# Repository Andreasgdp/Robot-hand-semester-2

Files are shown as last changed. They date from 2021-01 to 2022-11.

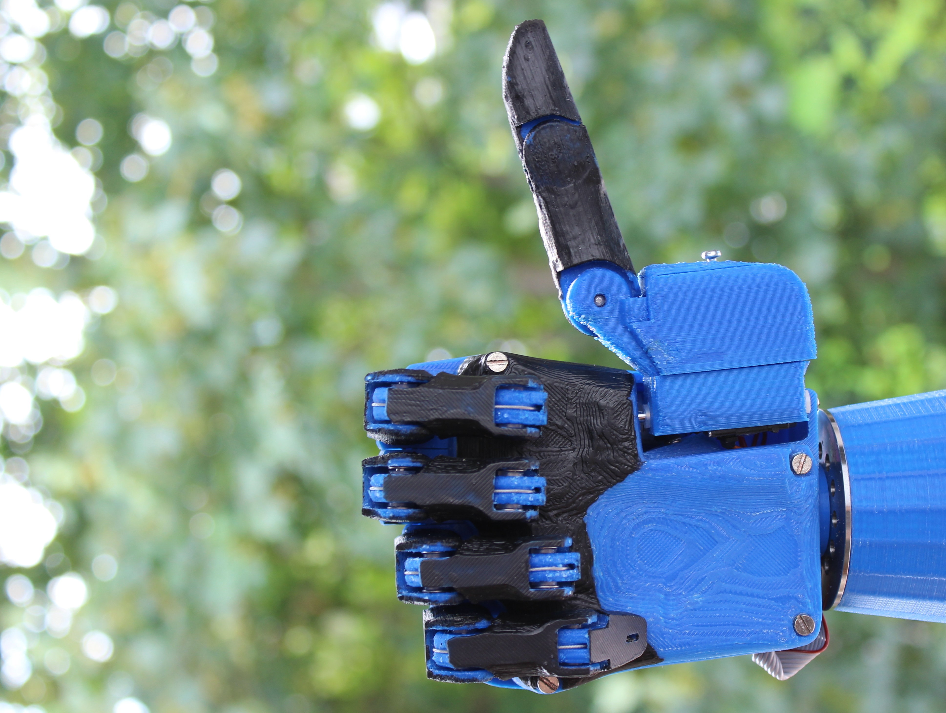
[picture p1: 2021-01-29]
images_readme/robot_hand.jpg

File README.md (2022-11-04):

<!--
*** Thanks for checking out this README Template. If you have a suggestion that would
*** make this better, please fork the repo and create a pull request or simply open
*** an issue with the tag "enhancement".
*** Thanks again! Now go create something AMAZING! :D
***
***
***
*** To avoid retyping too much info. Do a search and replace for the following:
*** andreasgdp, Robot-hand-semester-2, AndreasGuldberg, andreasgdp@gmail.com
-->

<!-- PROJECT SHIELDS -->
<!--
*** I'm using markdown "reference style" links for readability.
*** Reference links are enclosed in brackets [ ] instead of parentheses ( ).
*** See the bottom of this document for the declaration of the reference variables
*** for contributors-url, forks-url, etc. This is an optional, concise syntax you may use.
*** https://www.markdownguide.org/basic-syntax/#reference-style-links
-->
[][contributors-url]
[][forks-url]
[][stars-url]
[][issues-url]
[][license-url]
[][linkedin-url]
<!-- ABOUT THE PROJECT -->
## About The Project
<p align="center"> 
Gripper 
</p>

### Abstract
In this project, we have worked to make a gripper that can be mounted on and integrated
with a UR5 robot. The gripper has been 3D modelled, 3D printed and mounted on a UR5 robot.
The gripper is controlled by the movements of a motor located in the center of the gripper. The engine receives signals
to go in each direction at varying speed from an electrical circuit which receives signals from
a C++ program running on a Raspberry Pi. We have made a URCaps extension for ours
grabs a UR5. We have made an XML-RPC server running on a Raspberry Pi to be able to
communicate with the URCaps extension. With this XML-RPC communication we have the opportunity to
to control the gripper from a UR program running on the UR5 robot with our URCaps extension.
We have also made a GUI running alongside the server on the Raspberry Pi that we can use
to control the gripper directly.

### Built With

* [C++]()
* [Pure manpower]()

<!-- MARKDOWN LINKS & IMAGES -->
<!-- https://www.markdownguide.org/basic-syntax/#reference-style-links -->
[contributors-shield]: https://img.shields.io/github/contributors/andreasgdp/Robot-hand-semester-2.svg?style=flat-square
[contributors-url]: https://github.com/andreasgdp/Robot-hand-semester-2/graphs/contributors
[forks-shield]: https://img.shields.io/github/forks/andreasgdp/Robot-hand-semester-2.svg?style=flat-square
[forks-url]: https://github.com/andreasgdp/Robot-hand-semester-2/network/members
[stars-shield]: https://img.shields.io/github/stars/andreasgdp/Robot-hand-semester-2.svg?style=flat-square
[stars-url]: https://github.com/andreasgdp/Robot-hand-semester-2/stargazers
[issues-shield]: https://img.shields.io/github/issues/andreasgdp/Robot-hand-semester-2.svg?style=flat-square
[issues-url]: https://github.com/andreasgdp/Robot-hand-semester-2/issues
[license-shield]: https://img.shields.io/github/license/andreasgdp/Robot-hand-semester-2.svg?style=flat-square
[license-url]: https://github.com/andreasgdp/Robot-hand-semester-2/blob/master/LICENSE.txt
[linkedin-shield]: https://img.shields.io/badge/-LinkedIn-black.svg?style=flat-square&logo=linkedin&colorB=555
[linkedin-url]: https://www.linkedin.com/in/andreas-g-d-petersen-11707518b/
[product-screenshot]: images_readme/robot_hand.jpg

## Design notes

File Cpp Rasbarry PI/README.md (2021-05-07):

# Cpp program to run on Rasberry PI and PC
1. Create a QT application to get a GUI.
2. In the .pro file of the project you must include this:
-----------------------------------------------
  # WiringPi Libary
  INCLUDEPATH += /home/pi/sysroot/usr/include/
  LIBS += -L"/home/pi/sysroot/usr/lib"
  LIBS += -lwiringPi
-----------------------------------------------
This is the the library that gives control of the PI.

3. This library may need to be build in the terminal. Follow this: http://wiringpi.com/download-and-install/
4. To get the server working you must build the XML-RPC library. Follow this: http://xmlrpc-c.sourceforge.net 
5. Again you must include the library in the .pro file
-----------------------------------------------
  # XML-RPC Library
  LIBS += -Lusr/local/lib/ -lxmlrpc++
  LIBS += -Lusr/local/lib/ -lxmlrpc_util++
  LIBS += -Lusr/local/lib/ -lxmlrpc_server++
  LIBS += -Lusr/local/lib/ -lxmlrpc_server_abyss++
-----------------------------------------------

6. Now you should have everything needed to make the program.

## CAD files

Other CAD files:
3D-model gripper/Parts/Griber v1.f3d
3D-model gripper/Parts/Griber v2.f3d
3D-model gripper/Parts/Griber v21.f3d
3D-model gripper/Parts/Griber v3.f3d
3D-model gripper/Parts/Griber v4.f3d
3D-model gripper/Parts/Griber v5.f3d
3D-model gripper/Parts/Griber v6.f3d
3D-model gripper/Parts/Griber v7.f3d
3D-model gripper/Parts/Gripper n' Holder v1.f3z
3D-model gripper/Parts/Gripper n' Holder v5.f3z
3D-model gripper/Parts/Test motor v1.f3d
3D-model gripper/Parts/ToolFlange now with constraints v7.f3d
3D-model gripper/Parts/ToolFlange now with constraints v8.f3d
3D-model gripper/Parts/motor mount v9.f3z

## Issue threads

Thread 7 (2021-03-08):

First prototype of 3D-model of gripper in fusion

Andreasgdp, 2021-03-08:
**Describe the solution you'd like**
A clear and concise description of what you want to happen.

- Requirements for gripper
    - 2 active fingers

- [ ]  Create 3D-model of finges
- [ ]  Create 3D-model of Base
- [ ]  Use joints to attatch fingers to base

**Additional context**
Add any other context or screenshots about the feature request here.

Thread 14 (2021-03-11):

Create a TCP socket and server

Piekut99, 2021-03-11:
**Is your feature request related to a problem? Please describe.**
A clear and concise description of what the problem is. Ex. I'm always frustrated when [...]

**Describe the solution you'd like**
A clear and concise description of what you want to happen.

**Describe alternatives you've considered**
A clear and concise description of any alternative solutions or features you've considered.

**Additional context**
Add any other context or screenshots about the feature request here.

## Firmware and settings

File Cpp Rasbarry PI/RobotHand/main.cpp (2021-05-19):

#include "MainWindow.h"
#include <QApplication>

#define WIN32_LEAN_AND_MEAN

#include <iostream>
#include <stdexcept>
#include <cassert>
#include <string>
#include <thread>
#include "gripper.h"
#include <wiringPi.h> /* include wiringPi library */
#include <stdio.h>
#include <softPwm.h>  /* include header file for software PWM */

#ifdef _WIN32
#include <windows.h>
#else
#include <unistd.h>
#endif

#include <xmlrpc-c/base.hpp>
#include <xmlrpc-c/registry.hpp>
#include <xmlrpc-c/server_abyss.hpp>

#ifdef _WIN32
#define SLEEP(seconds) SleepEx(seconds * 1000);
#else
#define SLEEP(seconds) sleep(seconds);
#endif

//Create a gripper object
Gripper gripper;

class ConnCheck : public xmlrpc_c::method {
public:
    ConnCheck() {
        this->_signature = "i:";
        this->_help = "Connection check function";
    }
    void execute(xmlrpc_c::paramList const& paramList, xmlrpc_c::value* const retvalP) {
        std::cout << "Connection check!" << std::endl;

        *retvalP = xmlrpc_c::value_int(42);
    }
};

class Grip : public xmlrpc_c::method {
public:
    Grip() {
        this->_signature = "i:";
        this->_help = "Grip function";
    }
    void execute(xmlrpc_c::paramList const& paramList, xmlrpc_c::value* const retvalP) {

        std::string const width(paramList.getString(0));
        std::string const speed(paramList.getString(1));
        std::string const force(paramList.getString(2));
        paramList.verifyEnd(3);

        std::cout << "Grip! - " << "Width: " << width << ", Speed: " << speed << ", Force: " << force << std::endl;

        gripper.grip(width, speed, force);
        SLEEP(2); // Call gripper function with parameters

        *retvalP = xmlrpc_c::value_int(42);
    }
};

class Release : public xmlrpc_c::method {
public:
    Release() {
        this->_signature = "i:";
        this->_help = "Release function";
    }
    void execute(xmlrpc_c::paramList const& paramList, xmlrpc_c::value* const retvalP) {
        std::string const width(paramList.getString(0));
        std::string const speed(paramList.getString(1));
        paramList.verifyEnd(2);

        std::cout << "Release! - " << "Width: " << width << ", Speed: " << speed << std::endl;

        gripper.release(width, speed);
        SLEEP(2); // Call gripper function with parameters

        *retvalP = xmlrpc_c::value_int(42);
    }
};

void server(){
    std::cout << "Starting XML_RPC Server" << std::endl;
    try {
        xmlrpc_c::registry myRegistry;

        xmlrpc_c::methodPtr const connCheck(new ConnCheck);
        xmlrpc_c::methodPtr const grip(new Grip);
        xmlrpc_c::methodPtr const release(new Release);

        myRegistry.addMethod("connCheck", connCheck);
        myRegistry.addMethod("grip", grip);
        myRegistry.addMethod("release", release);

        xmlrpc_c::serverAbyss myAbyssServer(xmlrpc_c::serverAbyss::constrOpt().registryP(&myRegistry).portNumber(5000));

        myAbyssServer.run();

        assert(false);

    }  catch (std::exception const& e) {
        std::cerr << "Something failed. " << e.what() << std::endl;
    }
}

void motorRamp(){
    int PWM_pin     = 18;                /* GPIO0 as per WiringPi,GPIO18 as per BCM */
    int PIN_close   = 17;
    int PIN_open    = 27;
    int PIN_dead    = 22;
    int intensity   = gripper.getSpeed();
    bool deadBtn    = false;

    wiringPiSetupGpio();                /* initialize wiringPi setup */
    pinMode(PWM_pin,OUTPUT);        /* set GPIO as output */
    pinMode(PIN_close, OUTPUT);
    pinMode(PIN_open, OUTPUT);
    pinMode(PIN_dead, INPUT);
    softPwmCreate(PWM_pin,1,100);	/* set PWM channel along with range*/
    while (1) {
        while (gripper.getRun() == 2 && digitalRead(PIN_dead) == LOW) { // This is output for close
            intensity = gripper.getSpeed();
            digitalWrite(PIN_close, HIGH);
            digitalWrite(PIN_open, LOW);
            softPwmWrite (PWM_pin, intensity);
        }
        while (gripper.getRun() == 1 && digitalRead(PIN_dead) == LOW) { // This is output for open
            intensity = gripper.getSpeed();
            digitalWrite(PIN_close, LOW);
            digitalWrite(PIN_open, HIGH);
            softPwmWrite (PWM_pin, intensity);
        }
        while (gripper.getRun() == 0 || deadBtn) { // This is a resting state
            softPwmWrite (PWM_pin, intensity);
            digitalWrite(PIN_close, LOW);
            digitalWrite(PIN_open, LOW);
            if (deadBtn || digitalRead(PIN_dead) == HIGH){
                gripper.setRun(0);
                std::cout << "DEATH!" << std::endl;
                deadBtn = false;
                delay(100);
            }
        }
        while (digitalRead(PIN_dead) == HIGH && !deadBtn) {
            delay(50);
            if (digitalRead(PIN_dead) == HIGH)
                deadBtn = true;
        }
    }
}
int main(int argc, char *argv[])
{
    std::thread first (server);
    std::thread second (motorRamp);
    QApplication a(argc, argv);
    MainWindow w;
    w.show();

    return a.exec();
}

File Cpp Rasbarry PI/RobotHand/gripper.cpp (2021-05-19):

#include "gripper.h"
#include <iostream>
#include <cmath>
#include <wiringPi.h> /* include wiringPi library */
#include <stdio.h>
#include <softPwm.h>  /* include header file for software PWM */

// Initialize static member variables
int Gripper::_width{0};
int Gripper::_speed{100};
int Gripper::_force{0};
int Gripper::_run{0};


Gripper::Gripper() {
}

Gripper::~Gripper() {
    _width = 0;
    _speed = 0;
    _force = 0;
    _run = 0;
    wiringPiSetupGpio();       /* initialize wiringPi setup */
    pinMode(18,OUTPUT);        /* set GPIO as output */
    pinMode(17, OUTPUT);
    pinMode(27, OUTPUT);

    softPwmCreate(0,1,100);
    softPwmWrite (0, 0);
    std::cout << "Gripper is destructed" << std::endl;
}

void Gripper::setWidth(int width) {
    _width = width;
}

int Gripper::getWidth() {
    return _width;
}

int Gripper::getRun() {
    return _run;
}

int Gripper::getSpeed() {
    return _speed;
}

void Gripper::setSpeed(int speed) {
    _speed = speed;
}

void Gripper::setRun(int value)
{
    _run = value;
}

void Gripper::grip(std::string width, std::string speed, std::string force) {
    int vWidth = lrint(stod(width)*scale);
    int vSpeed = lrint(stod(speed)*scale);
    int vForce = lrint(stod(force)*scale);
    _run = 1;
    _speed = vSpeed;
    while (_run == 1) {

    }
    std::cout << "grip done" << std::endl;

}

void Gripper::release(std::string width, std::string speed) {
    int vWidth = lrint(stod(width)*scale);
    int vSpeed = lrint(stod(speed)*scale);
    _speed = vSpeed;
    _run = 2;
    while (_run == 2) {

    }

    std::cout << "release done" << std::endl;

}

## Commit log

2021-03-08 Create Digital UR+ gripper.docx
2021-03-08 Added folder for gripper
2021-03-10 Added Raspberry PI OS
2021-03-11 Hello World Sample
2021-03-16 Added doc and driver exampels
2021-03-16 Remove screwdriver
2021-03-16 Rename of gripper folder and removal of crap
2021-03-16 Version 1 of gripper
    [Griber v1.f3d]
2021-03-17 Griber v2
    [Griber v2.f3d]
2021-03-23 Mad some parts 3d printer freindly
    [Griber v3.f3d]
2021-03-24 Createde fingers for can, and connections for fingers
    [Griber v4.f3d]
2021-03-25 added some funktions for thickness
    [Griber v5.f3d]
2021-04-01 Mount added
    [ToolFlange now with constraints v7.f3d]
2021-04-06 Gripper v6
    [Griber v6.f3d]
2021-04-06 The first 3d printed gripper
    [Griber v7.f3d]
2021-04-06 change motor holes
    [ToolFlange now with constraints v8.f3d]
2021-04-07 print ready (hopefully)
    [Griber v21.f3d, motor mount v9.f3z]
2021-04-13 Speed varibale in Pwm
2021-04-27 better bolt cuts
    [Gripper n' Holder v1.f3z, Gripper n' Holder v5.f3z]
2021-04-27 Motor working both ways and we have a DEATH buttom!

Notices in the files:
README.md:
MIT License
